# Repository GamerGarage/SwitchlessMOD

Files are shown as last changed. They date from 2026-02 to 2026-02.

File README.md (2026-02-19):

# Sega Mega Drive - PIC16F684 Switchless Region & Reset Mod

Este proyecto contiene el firmware en C para un microcontrolador PIC16F684 diseñado específicamente para realizar un mod "switchless" (sin interruptores físicos) en la **Sega Mega Drive** (o Genesis). 

Permite controlar el reinicio y cambiar la región (PAL/JAP/USA) de la consola utilizando únicamente el botón de RESET original. Además, utiliza un LED RGB para indicar visualmente en qué región se encuentra el sistema en cada momento.

## 🚀 Características

* **Control con un solo botón:** Discrimina entre pulsaciones cortas (reinicio) y pulsaciones largas (cambio de región) interceptando el botón de RESET original de la Mega Drive.
* **Memoria EEPROM:** Guarda la última región seleccionada para que la consola arranque con ella la próxima vez que se encienda.
* **Indicador LED RGB:** Muestra visualmente la región actual (Rojo = PAL, Verde = JAP, Azul = USA). Sustituye al LED rojo original de la consola.
* **Antirrebote por software:** Evita falsas pulsaciones y reinicios accidentales.

## 🧩 Circuito Impreso (PCB) Personalizado y Gerbers

Para facilitar la instalación y hacerla lo más limpia posible, he diseñado una placa de circuito impreso (PCB) a medida para este mod.

### Vista de la PCB
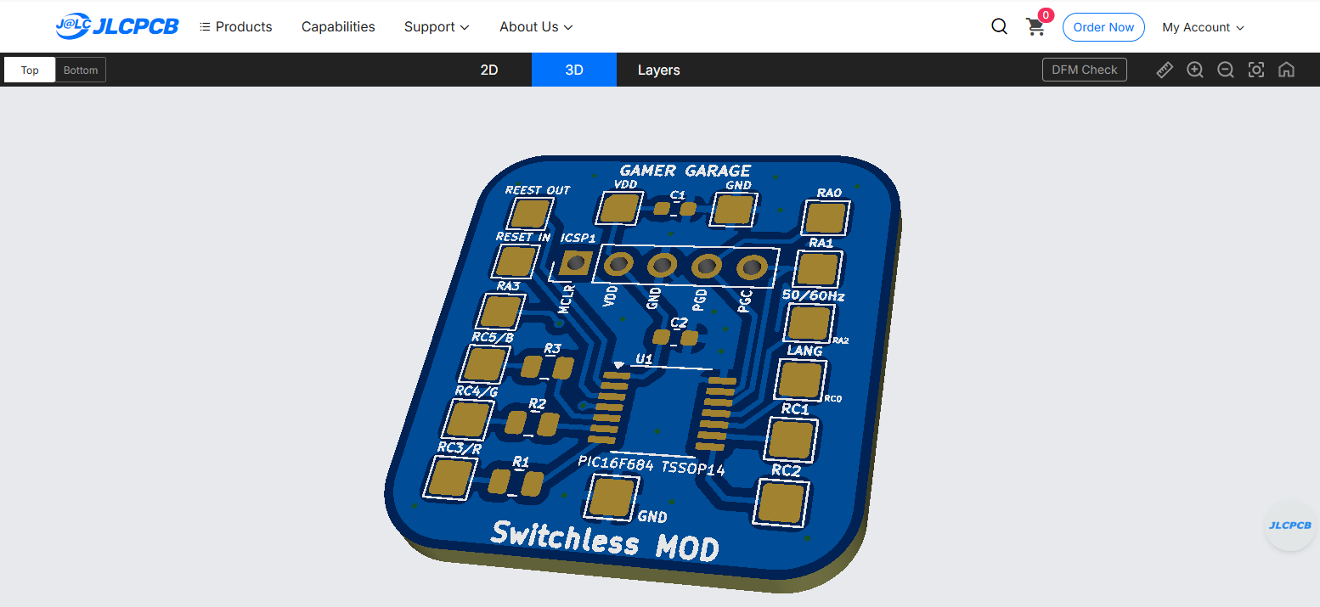
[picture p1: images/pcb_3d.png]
Vista 3D de la PCB


### Esquemático (KiCad)
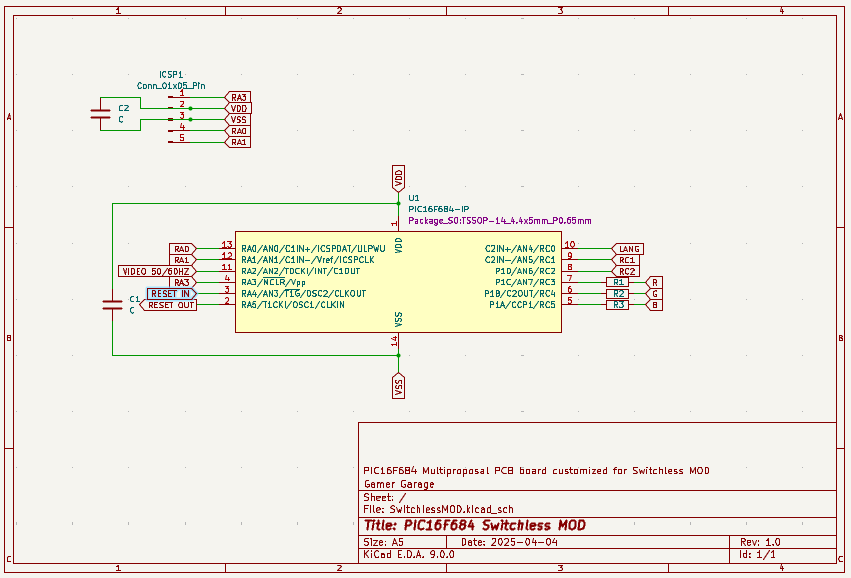
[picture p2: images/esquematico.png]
Esquemático del circuito


* **Descarga de Gerbers:** Puedes descargar los archivos **Gerber** incluidos en este repositorio para pedir tus placas en JLCPCB, PCBWay, etc.
* **Resistencias LED RGB:** Deben ir soldadas exactamente en las posiciones marcadas como **R1, R2 y R3** en la serigrafía.
* **Uso Multipropósito (Breakout Board):** El diseño de la placa es genérico. Si puenteas con estaño las posiciones de las resistencias R1, R2 y R3, puedes usar esta PCB como un adaptador genérico para cualquier otro proyecto con el PIC16F684.
* **Puerto de Programación (ICSP):** La placa incluye pines para programar el PIC directamente sobre la PCB con un PICkit 3.

## ⚙️ Funcionamiento de la Intercepción del Reset

El PIC actúa como un "intermediario" entre el botón físico de la consola y el procesador. 

1.  **Pulsación Corta (menos de 2 segundos):** El PIC detecta la pulsación y transmite una señal de reinicio (LOW) al procesador durante 200ms. Funciona como un reset tradicional.
2.  **Pulsación Larga (más de 2 segundos):** El PIC **NO** envía la señal de reinicio a la consola. En su lugar, entra en el "Modo de Selección" de región. 
    * El LED RGB ciclará entre los tres colores cada 500ms.
    * Al soltar el botón en el color deseado, la selección se guarda en la EEPROM y cambia la región al instante, sin reiniciar el juego.

### Zonas y Colores
| Región | Video | Idioma | Color LED RGB |
| :--- | :--- | :--- | :--- |
| **PAL (Europa)** | 50Hz (0) | Inglés (1) | 🔴 Rojo |
| **JAP (Japón)** | 60Hz (1) | Japonés (0) | 🟢 Verde |
| **USA (América)**| 60Hz (1) | Inglés (1) | 🔵 Azul |

## 🔌 Conexiones de la PCB al Hardware

La serigrafía de mi PCB está diseñada para ser intuitiva. Aquí tienes la correspondencia de los pads con los puntos de soldadura en la consola:

| Pad en la PCB | Pin PIC | Función / Conexión en la Mega Drive |
| :--- | :---: | :--- |
| **RESET IN** | `RA4` | Al botón físico de Reset (la parte que va a GND al pulsar). |
| **RESET OUT** | `RA5` | Al punto de la pista de Reset que va hacia el procesador principal. |
| **LANG** | `RC0` | Al punto del jumper de configuración de Idioma. |
| **50/60hz** | `RA2` | Al punto del jumper de configuración de Frecuencia. |
| **RC3/R** | `RC3` | Al ánodo Rojo del LED RGB (vía resistencia R1). |
| **RC4/G** | `RC4` | Al ánodo Verde del LED RGB (vía resistencia R2). |
| **RC5/B** | `RC5` | Al ánodo Azul del LED RGB (vía resistencia R3). |
| **VCC** | `VDD` | Alimentación de +5V de la consola. |
| **GND** | `VSS` | Tierra (GND) de la consola. |

*Nota: El cátodo común del LED RGB se conecta a cualquiera de los pads **GND** extra disponibles en la PCB.*

## ✂️ Guía de Instalación: Ejemplo Placa IC BD M5 PAL / VA6

⚠️ **IMPORTANTE:** Es **ESTRICTAMENTE NECESARIO** cortar pistas en la placa base original. Si conectas el PIC sin aislar los pines, provocarás un cortocircuito que podria dañará la consola o el microcontrolador.

Para ilustrar el proceso, aquí tienes mi propia instalación en una revisión **VA6**:

### 1. Intercepción del botón RESET
Debes localizar la pista que une el botón de Reset con el procesador y **cortarla**. 
* El lado de la pista que viene del botón físico se suelda al pad **RESET IN** de la PCB.
* El lado de la pista que va hacia el procesador se suelda al pad **RESET OUT** de la PCB.

### 2. Configuración de Región (Jumpers)
En la revisión VA6, el idioma y la frecuencia vienen fijados por los jumpers **JP2** y **JP3**. 
* **Cortar pistas:** Corta la pista de cobre que une los pads de estos jumpers para romper la conexión de fábrica (+5V y GND). Comprueba con un multímetro que están aislados.
* **Conexión de señales:** Suelda los pads **LANG** y **50/60hz** del mod a los puntos correspondientes de los jumpers que van hacia el chip de video.
* **Alimentación:** Puedes aprovechar el otro extremo de los jumpers cortados para alimentar el mod. El lado cortado de JP2 te dará los +5V (suelda a **VCC**) y el lado cortado de JP3 te dará la masa (suelda a **GND**).

Corte de pistas JP2, JP3 y Reset
Instalación finalizada con PCB

## 🛠️ Compilación y Programación

* **IDE:** MPLAB X IDE
* **Compilador:** XC8 Compiler
* **Frecuencia del Oscilador:** 4MHz (Oscilador Interno)

Utiliza un programador como el **PICkit 3** conectándolo a los pines ICSP de la PCB para flashear el archivo `.hex`.

## ⚠️ Advertencia Legal y de Hardware
Modificar hardware original conlleva riesgos. Asegúrate de tener conocimientos de electrónica y revisar bien los puntos de corte de tu revisión específica de placa base (VA0, VA4, VA6, etc.) antes de proceder. El software y los esquemas se proporcionan "tal cual". No me hago responsable por daños ocasionados a tu equipo.

---

## 👨‍💻 Autor y Contacto

Creado por **Javi** de **GAMER GARAGE**. 

Si te ha resultado útil este mod o quieres ver más proyectos de reparación, modificación y electrónica retro, pásate por mi web:
🌐 **[www.gamergarage.es](https://www.gamergarage.es)**

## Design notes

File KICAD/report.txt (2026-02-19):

Plotted to 'C:\Users\BDM_PC\Documents\Proyectos PCB\Switchless MOD\SwitchlessMOD\SwitchlessMOD-F_Cu.gbr'.
Plotted to 'C:\Users\BDM_PC\Documents\Proyectos PCB\Switchless MOD\SwitchlessMOD\SwitchlessMOD-B_Cu.gbr'.
Plotted to 'C:\Users\BDM_PC\Documents\Proyectos PCB\Switchless MOD\SwitchlessMOD\SwitchlessMOD-F_Paste.gbr'.
Plotted to 'C:\Users\BDM_PC\Documents\Proyectos PCB\Switchless MOD\SwitchlessMOD\SwitchlessMOD-B_Paste.gbr'.
Plotted to 'C:\Users\BDM_PC\Documents\Proyectos PCB\Switchless MOD\SwitchlessMOD\SwitchlessMOD-F_Silkscreen.gbr'.
Plotted to 'C:\Users\BDM_PC\Documents\Proyectos PCB\Switchless MOD\SwitchlessMOD\SwitchlessMOD-B_Silkscreen.gbr'.
Plotted to 'C:\Users\BDM_PC\Documents\Proyectos PCB\Switchless MOD\SwitchlessMOD\SwitchlessMOD-F_Mask.gbr'.
Plotted to 'C:\Users\BDM_PC\Documents\Proyectos PCB\Switchless MOD\SwitchlessMOD\SwitchlessMOD-B_Mask.gbr'.
Plotted to 'C:\Users\BDM_PC\Documents\Proyectos PCB\Switchless MOD\SwitchlessMOD\SwitchlessMOD-Edge_Cuts.gbr'.
Created Gerber job file 'C:\Users\BDM_PC\Documents\Proyectos PCB\Switchless MOD\SwitchlessMOD\SwitchlessMOD-job.gbrjob'.
Info: Done.

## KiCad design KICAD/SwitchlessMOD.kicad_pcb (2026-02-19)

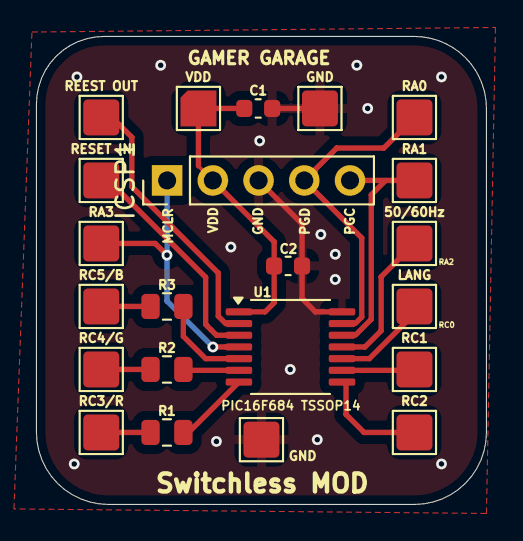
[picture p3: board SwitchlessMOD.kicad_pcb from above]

Board: 2 copper layers, 25.0 x 26.0 mm, 22 parts (0 on the bottom side), 17 nets.

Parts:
50/60Hz: TestPoint_Pad_2.0x2.0mm
C1, C2: C; C_0603_1608Metric
GND: TestPoint_Pad_2.0x2.0mm
GND#2: TestPoint_Pad_2.0x2.0mm
ICSP1: Conn_01x05_Pin; PinHeader_1x05_P2.54mm_Vertical
LANG: TestPoint_Pad_2.0x2.0mm
R1, R2, R3: R; R_0805_2012Metric
RA0, RA1, RA3: TestPoint_Pad_2.0x2.0mm
RC1, RC2, RC3/R, RC4/G, RC5/B: TestPoint_Pad_2.0x2.0mm
REEST OUT: TestPoint_Pad_2.0x2.0mm
RESET IN: TestPoint_Pad_2.0x2.0mm
U1: PIC16F684-IP; TSSOP-14_4.4x5mm_P0.65mm
VDD: TestPoint_Pad_2.0x2.0mm

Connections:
B: R3.2, RC5/B.5
G: R2.2, RC4/G.6
LANG: LANG.10, U1.10 (C2IN+/AN4/RC0)
unnamed: R3.1, U1.5 (P1A/CCP1/RC5)
unnamed: R2.1, U1.6 (P1B/C2OUT/RC4)
unnamed: R1.1, U1.7 (P1C/AN7/RC3)
R: R1.2, RC3/R.7
RA0: ICSP1.4, RA0.13, U1.13 (RA0/AN0/C1IN+/ICSPDAT/ULPWU)
RA1: ICSP1.5, RA1.12, U1.12 (RA1/AN1/C1IN-/Vref/ICSPCLK)
RA3: ICSP1.1, RA3.4, U1.4 (RA3/~MCLR/Vpp)
RC1: RC1.9, U1.9 (C2IN-/AN5/RC1)
RC2: RC2.8, U1.8 (P1D/AN6/RC2)
RESET IN: RESET IN.3, U1.3 (RA4/AN3/~T1G/OSC2/CLKOUT)
RESET OUT: REEST OUT.2, U1.2 (RA5/T1CKI/OSC1/CLKIN)
VDD: C1.1, C2.1, ICSP1.2, U1.1 (VDD), VDD.1
VIDEO 50/60HZ: 50/60Hz.11, U1.11 (RA2/AN2/T0CKI/INT/C1OUT)
VSS: C1.2, C2.2, GND.14, GND#2.14, ICSP1.3, U1.14 (VSS)

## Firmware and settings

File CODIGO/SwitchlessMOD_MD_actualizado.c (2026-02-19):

/*
 * ----------------------------------------------------------------------------
 * Sega Mega Drive - PIC16F684 Switchless Region & Reset Mod
 * ----------------------------------------------------------------------------
 * Autor:   Javi (GAMER GARAGE)
 * Web:     https://www.gamergarage.es
 * Versión: 1.0
 * * Descripción: 
 * Firmware para controlar el reinicio y la región (PAL/JAP/USA) de una 
 * consola Sega Mega Drive/Genesis utilizando el botón de RESET original
 * y un indicador LED RGB.
 * * Licencia: MIT (Puedes usar, modificar y distribuir este código libremente, 
 * siempre y cuando se mantenga la mención al autor original).
 * ----------------------------------------------------------------------------
 */

// PIC16F684 Configuration Bit Settings
#pragma config FOSC = INTOSCIO  // Oscilador interno activado
// ... (aquí sigue tu código normal)

// PIC16F684 Configuration Bit Settings
#pragma config FOSC = INTOSCIO  // Oscilador interno activado
#pragma config WDTE = OFF       // Watchdog Timer desactivado
#pragma config PWRTE = OFF      // Power-up Timer desactivado
#pragma config MCLRE = OFF      // Pin MCLR configurado como pin de I/O digital
#pragma config CP = OFF         // Protección de código desactivada
#pragma config CPD = OFF        // Protección de datos desactivada
#pragma config BOREN = OFF      // Brown-out Reset desactivado
#pragma config IESO = ON        // Internal External Switchover activado
#pragma config FCMEN = ON       // Fail-Safe Clock Monitor activado

#include <xc.h>
#include <stdio.h>
#include <pic16f684.h>

// Definición de la frecuencia del oscilador para el uso de la función __delay_ms()
#define _XTAL_FREQ 4000000

// Asignación de pines para el LED RGB indicador de región
#define LED_RED    RC3
#define LED_GREEN  RC4
#define LED_BLUE   RC5

// Asignación de pines para el control de Reset
#define RESET_IN   RA4  // Botón de entrada para el reset y cambio de región
#define RESET_OUT  RA5  // Salida que ejecuta el reset físico en la consola

// Asignación de pines para la configuración de región (Idioma y Video)
#define LANGUAGE   RC0
#define VIDEO      RA2

// Constantes arbitrarias para identificar cada región en la EEPROM
#define PAL        0x50
#define JAP        0x4A
#define USA        0x55

/**
 * Guarda el modo de región actual en la memoria EEPROM.
 */
void saveMode(unsigned char dir, unsigned char data) {
    eeprom_write(dir, data);
}

/**
 * Configura las salidas y el LED para el modo PAL (Europa).
 */
void setPAL(void){
    LANGUAGE = 1;
    VIDEO = 0;
    LED_RED = 1;
    LED_GREEN = 0;
    LED_BLUE = 0;
}

/**
 * Configura las salidas y el LED para el modo JAP (Japón).
 */
void setJAP(void){
    LANGUAGE = 0;
    VIDEO = 1;
    LED_RED = 0;
    LED_GREEN = 1;
    LED_BLUE = 0;
}

/**
 * Configura las salidas y el LED para el modo USA (Estados Unidos).
 */
void setUSA(void){
    LANGUAGE = 1;
    VIDEO = 1;
    LED_RED = 0;
    LED_GREEN = 0;
    LED_BLUE = 1;
}

/**
 * Lee la memoria EEPROM y aplica la configuración de región guardada.
 * Si no reconoce el dato (ej. primera vez que se enciende), carga PAL por defecto.
 */
void loadMode(unsigned char dir) {
    unsigned char storedMode = eeprom_read(dir);
    
    switch (storedMode){
        case PAL:
            setPAL();
            break;
        case JAP:
            setJAP();
            break;
        case USA:
            setUSA();
            break;
        default:
            setPAL();          
    }
}

/**
 * Bucle de selección de región.
 * Cambia cíclicamente entre PAL, JAP y USA cada 500ms mientras el botón
 * se mantenga pulsado. Al soltarlo, guarda la selección final en la EEPROM.
 */
void changeMode(void){
    unsigned char selectedMode;
    // Mientras el botón esté presionado (!RESET_IN por el pull-up)
    while (!RESET_IN){
        setPAL(); 
        selectedMode = PAL;
        __delay_ms (500);
        if (RESET_IN) break; // Si se suelta el botón, salimos del bucle

        setJAP();    
        selectedMode = JAP;
        __delay_ms (500);
        if (RESET_IN) break;

        setUSA();  
        selectedMode = USA;
        __delay_ms (500);
        if (RESET_IN) break;
    }
    // Guardar el modo seleccionado en la dirección 0x00 de la EEPROM
    saveMode(0x00, selectedMode);
}

void main(void) {
    // Configuración inicial del microcontrolador
    ANSEL = 0;               // Desactiva todas las entradas analógicas (todo digital)
    TRISA = 0b00010000;      // Puerto A: RA4 como entrada (Botón), resto como salidas
    TRISC = 0b00000000;      // Puerto C: Todos los pines como salidas

    // Configuración de la resistencia Pull-up interna para el botón
    OPTION_REGbits.nRAPU = 0;  // Habilita el control global de los pull-ups en el Puerto A
    WPUA |= (1 << 4);          // Activa el pull-up específico en el pin RA4

    // Estado inicial seguro
    RESET_OUT = 1;           // Mantiene la señal de reset de la consola en estado inactivo

    // Cargar la última configuración de región guardada
    loadMode(0x00);

    int tiempo_pulsado = 0;

    // Bucle principal del programa
    while (1) {
        RESET_OUT = 1;              // Asegura que el RESET esté desactivado    
        int tiempo_pulsado = 0;     // Reinicia el contador de tiempo de pulsación

        // Bucle de espera activa: cuenta los milisegundos mientras el botón está pulsado
        while (!RESET_IN) {
            __delay_ms(1);
            tiempo_pulsado++;

            // Condición de Pulsación Larga: Modo de cambio de región (> 2 segundos)
            if (tiempo_pulsado >= 2000) {
                changeMode();

                // Esperar a que el usuario suelte el botón por completo antes de continuar
                while (!RESET_IN);     // Bucle infinito hasta que RESET_IN vuelva a ser 1
                __delay_ms(50);        // Pequeño retardo antirrebote
                break;                 // Salir de este bucle para volver al principal
            }
        }

        // Condición de Pulsación Corta: Ejecutar Reset de la consola (entre 20ms y 2s)
        if (tiempo_pulsado > 20 && tiempo_pulsado < 2000) {
            RESET_OUT = 0;            // Activar señal de reset (Lógica negativa)        
            __delay_ms(200);          // Mantener el reset presionado artificialmente por 200ms
            RESET_OUT = 1;            // Liberar el reset
        }

        // Pequeña espera antirrebote general al terminar cualquier acción
        __delay_ms(50);
    }
    
    return;

}

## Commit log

2026-02-19 Archivos del proyecto
    Se añaden los archivos de KiCAD, los gerber y el codigo fuente.
    [SwitchlessMOD-B_Cu.gbr, SwitchlessMOD-B_Mask.gbr, SwitchlessMOD-B_Paste.gbr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]
2026-02-19 Update README.md
    actaulizacion con imagenes pcb
2026-02-19 Add files via upload
    imagene pcb
